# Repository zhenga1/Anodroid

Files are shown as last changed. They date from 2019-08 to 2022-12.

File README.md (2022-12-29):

# Anodroid
v1_0_0
# We do not recommend this project to be used yet. It is only in its beginning stages and does risk failure. 

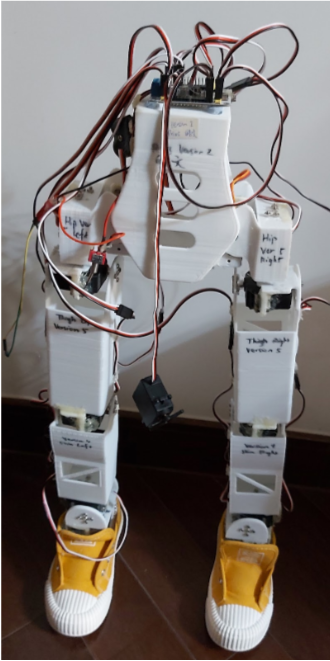
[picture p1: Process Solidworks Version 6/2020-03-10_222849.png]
<br/><br/>
Anodroid is a 10-DOF humanoid-robot. It is an integrated machine that can move around in flat and tilted surfaces. It consists of:
- 15 single axis model motors. 12 needed, 3 for backup
- 24 Circular rotating shafts for the motors, 12 needed, 12 for backup 
- 70 M3*7 screws and nuts, 60 needed, 10 for backup
- 20 sets of axial motor equipments, including an M3*10 screw, a rotating axis, and an M3 nut
- 70 M3*5 nuts and screws, 60 needed, 10 for backup
- An arduino controller board
- 60 sets of nuts and bolts for M4*8 screw, used to secure the screw and motor. 50 are needed, 10 are for backup
- Many rolls of PLA plastic, used for 3D printing
- A 3D printer and 3D printing software

Ideally, one should also have a recent version of DS Solidworks. 

The design files can be found in the root directory.

The **aim of this project** is to eventually allow the robot to posesss the ability to run and walk dynamically on flat and tilted surfaces. 

# EDIT: 
Anodroid is now a 12-DOF humanoid-robot. Two have been added on between the foot and shin parts to allow the robot to tilt left and right

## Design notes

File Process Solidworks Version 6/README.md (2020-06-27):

# Anodroid
v1_0_0
# We do not recommend this project to be used yet. It is only in its beginning stages and does risk failure. 

GitHub Logo
Anodroid is a 10-DOF humanoid-robot. It is an integrated machine that can walk and run, in flat surfaces, in tilted surfaces etcetera. It consists of:
- 13 single axis model motors. 10 needed, 3 for backup
- 20 Circular rotating shafts for the motors, 10 needed, 10 for backup 
- 60 M3*7 screws and nuts, 50 needed, 10 for backup
- 20 sets of axial motor equipments, including an M3*10 screw, a rotating axis, and an M3 nut
- 60 M3*5 nuts and screws, 50 needed, 10 for backup
- An arduino controller board
- 50 sets of nuts and bolts for M4*8 screw, used to secure the screw and motor. 40 are needed, 10 are for backup
- Many rolls of PLA plastic, used for 3D printing
- A 3D printer and 3D printing software

Ideally, one should also have a recent version of DS Solidworks. 

The design files can be found in the root directory:

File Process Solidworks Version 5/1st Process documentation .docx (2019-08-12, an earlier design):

Documents: Data in this laptop, kept in Computer/Documents(E:)

Process 1: Drawing the SR-1501:

Base of the diagram:

Assumptions:

- Assumed outside rectangle fillet radius 2.5
- Assumed tangency of the circles in the sides of the motor

Measured:

- Radius of the circle for the screw on the top of motor:2.34mm
- Distance of the circle for the screw to the center: 7.05mm
- Radius of the big circle on the top:20mm
- Thickness of the upwards circle: 2.06mm
- Side shape top length: 11.78mm
- Side shape middle length: 16.74mm
- Height of the bottom part of the spinny thing:3.6mm
- Height of the bottom part: 4.9mm
- Distance between the outside tangent part of circle to circle:1.84mm
- Radius of the bottom part of the upwards circle: 8.08mm
- Bottom shape length: 9.5mm
- Distance between the top of the upwards circle and the bottom: 6.3mm
- Width of the whole part:3.24mm
- Distance to the ends: 2.95
- Thickness of Holder: 2.2mm
- Connecting holes with Holder:4.32mm diameter

Wrong Assumptions:

- Assumed tangency of the circles in the sides of the motor, not tangent.

Holder motor hole to ends distance: 9.01mm

Actual motor hole to ends distance: 10mm

Height of motor assembly final:

51.5mm+ axis(1mm) = 52.5mm

Holder documentation:

Radius of circles: 2.76

Distance between them: 7.08

Connecting hole with Motor SR-1501: 3.8 diameter

Wrong

Holder dimensions are exactly the same as that of motor hole

Holder center to the end dimension: 42.4mm

Holder bottom holes: Radius 2.34 and distance between each other 9. Vertical with origin and distance from top is 23.

Pelvis:

- Length of motor hole: Original length+1+2*2+6 = 52. 5+4+1+6= 63 .6

Solidworks Feet specifications:

- Shell thickness: 2mm
- Length: 15mm
- Width: 5-7mm
- Shoe: Height of the highest is 6-7mm, max at the ends and min in the middle Max height distance is 4 and 3 respectively
- Shin Basic Documentation:
- Width of shin: Motor length + shell*2 = 52.5+2*2 = 56.5mm
- Width of shin should actually be motor length* shell*2 = 51.5+1+2*2 = 56.5
- Height of shin: 150mm
- Length of shin: 100mm
- Dimension of the shell thing: Multi-variable. 3mm for bottom and 1.7mm for everywhere else.

Shoe:

- Current dimensions only allow 33.7 space
- I want 39.24 space

Thigh Dimensions:

Height: 200mm

Length: 60mm

Width of shin: 51.5+2*2 = 55.5

Shell thickness: 2mm everywhere and 3mm at the bottom.

Additional space given for motor to turn: 39.24

Total amount of exact space needed: 38.24

Solidworks notes:

Properties:

- Rotate Entities: When you have two distinct distance dimensions between two points, that somehow rely on factors such as horizontal and vertical projections and shit. Thus, if you may need to rotate make sure you change these distances. This may include swapping them around, if the rotational angle is 90 degrees

Putting a point in the intersection of a line and a spline:

- Coincide the point with the line first, and then with the spline afterwards. Do this separately

Putting a point in the intersection of a line and a circle:

- Select all three sketch entities, and choose “make intersection”.

Chest Documentation:

1. Dimensions provided 30*17mm. My dimensions 54.5*20mm. Thus, need to make my thing a lot taller

2. Actual height of motor: 51.5mm

3. Their given space: 47mm - 2*2.7mm = 47mm - 5.4mm = 41.6mm. Thus, it needs to be 5.48mm wider. That halved is 2.74mm

Screw documentation:

Screw diameter measured major axis(including the thread): 2.94mm

Screw diameter minor axis: 2.34mm

Screw top(bolt part) width: 5mm

Screw length: 8.64mm

Screw head length; 2.04mm

Bottom of head of screw – End of screw fastener: 8.64-2.04 = 6.6mm

Amount of revolutions of the screw thread(螺纹数量): 12

Pitch of the screw thread(螺距):6.6mm/12 =0.55mm

Height of screw thread: 0.3mm

Length of my triangle for sweep cut: 0.52mm(basic trig)

Thread basics:

Major axis:

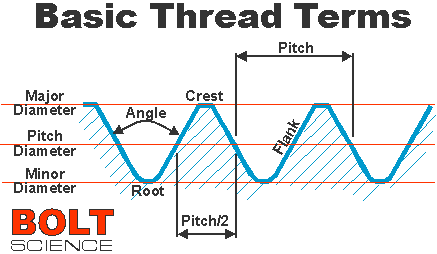
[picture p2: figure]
Image result for thread flank

Lead: Distance of screw threads along the axis that is covered by one complete rotation of the screw （周期）

Pitch: Distance between the crest of a thread to the next(螺距)

Typical screws are triangular, in the sense that the crest and the minor, the thread-form resembles a triangle, typically a isocellles one. This is called the “V- thread”

Male and female defines the direction in which the crest is facing(external-male) and (internal-female)

The M, denotes the largest diameter of the screw, the diameter of the major axis. Thus, M3 means 3 millimeters on the major axis

The second measurement denotes the pitch length, say 1.5mm.

The final measurement denotes the distance between the bottom of the head of the screw to the end of the fastener of the screw. This is, for instance, 30mm.

Very Useful image:

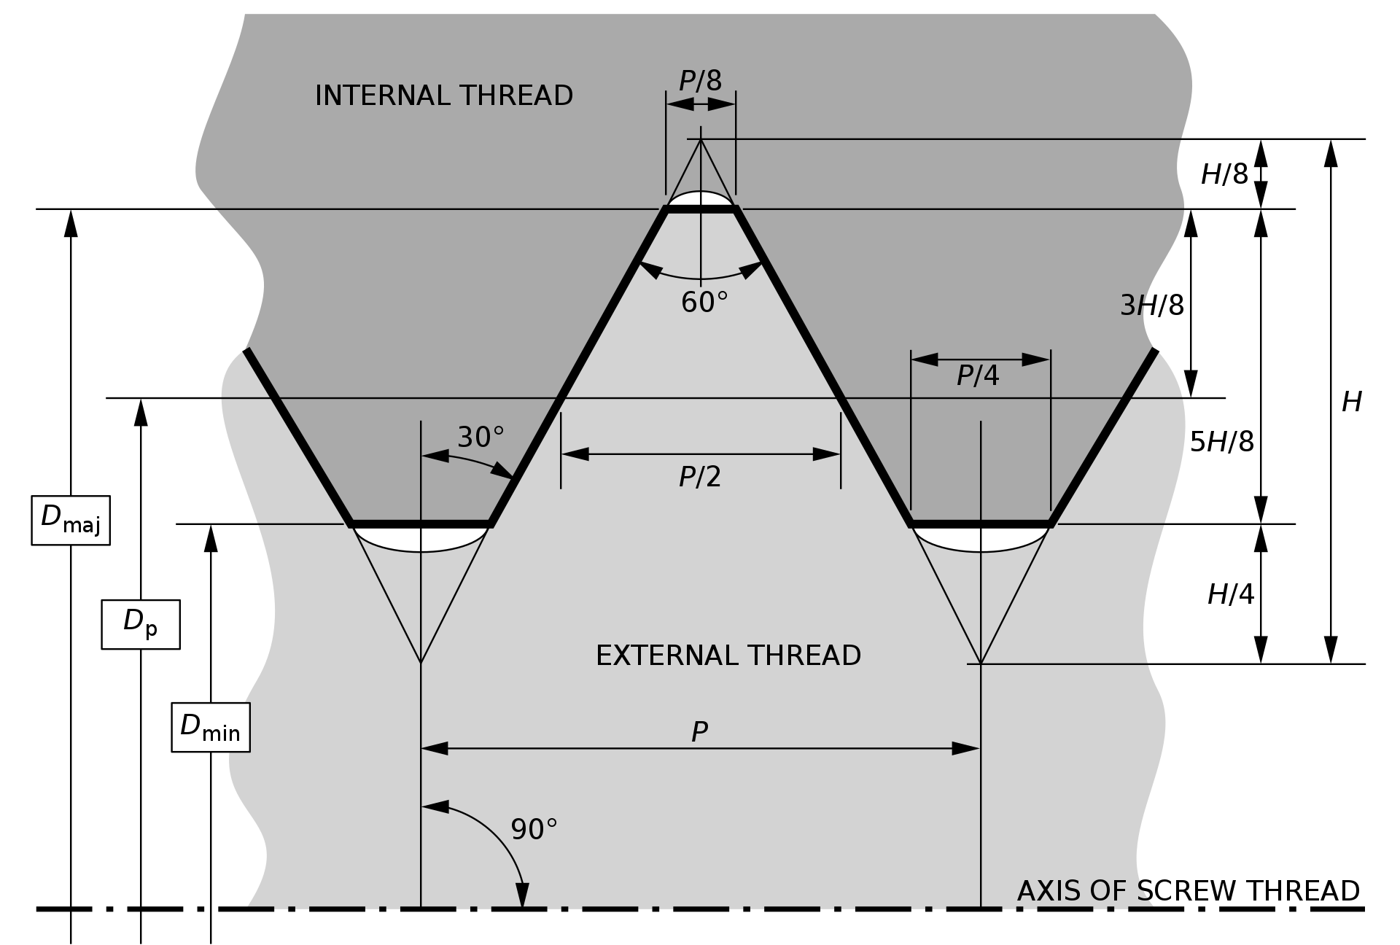
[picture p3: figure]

D – Denotes distance of major, pitch and minor diameter

P – pitch

H- height of screw

Types of screws that are necessary:

M3 screws and M4 screws

Solidworks problems:

- Cannot successfully rotate entities in sketch whilst keeping relations(no matter what)
- Cannot rotate a goddamn plane, say, 90 degrees around it’s origin
- Cannot delete coincident endpoints of two collinear lines.

Solidworks skills:

Special things:

Sketch flange:

https://www.youtube.com/watch?v=35gBHZ77z0I

Used to lift up the edge part of a sheet metal up vertically. Very cool.

Connector piece: Sheet metal turning radius: 1mm

Edge flange length: 20mm

View perspective will have the dimensions done wrong. Thus we need to disable the view of perspective.

Hip motor dimensions:

- It is primarily made of an intersection body
- Shortest width: 57.5mm
- Longest width required: 66.9mm\

Part 1(Hip connector): stats:

- Added an extrude from the outside of the part

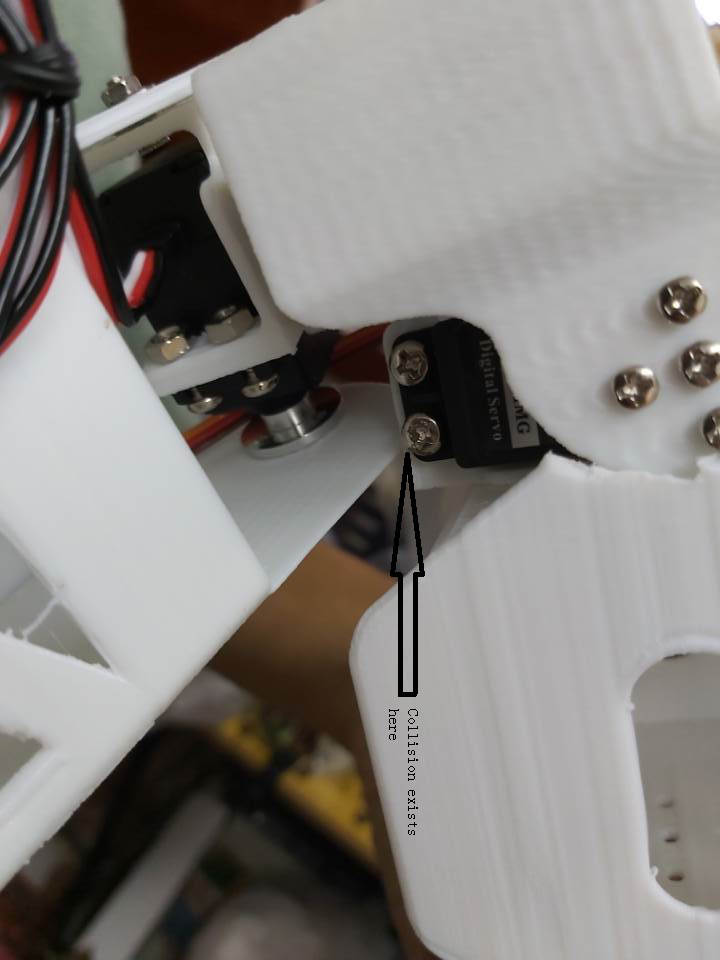
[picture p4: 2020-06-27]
Process Solidworks Version 6/Collisions.jpg

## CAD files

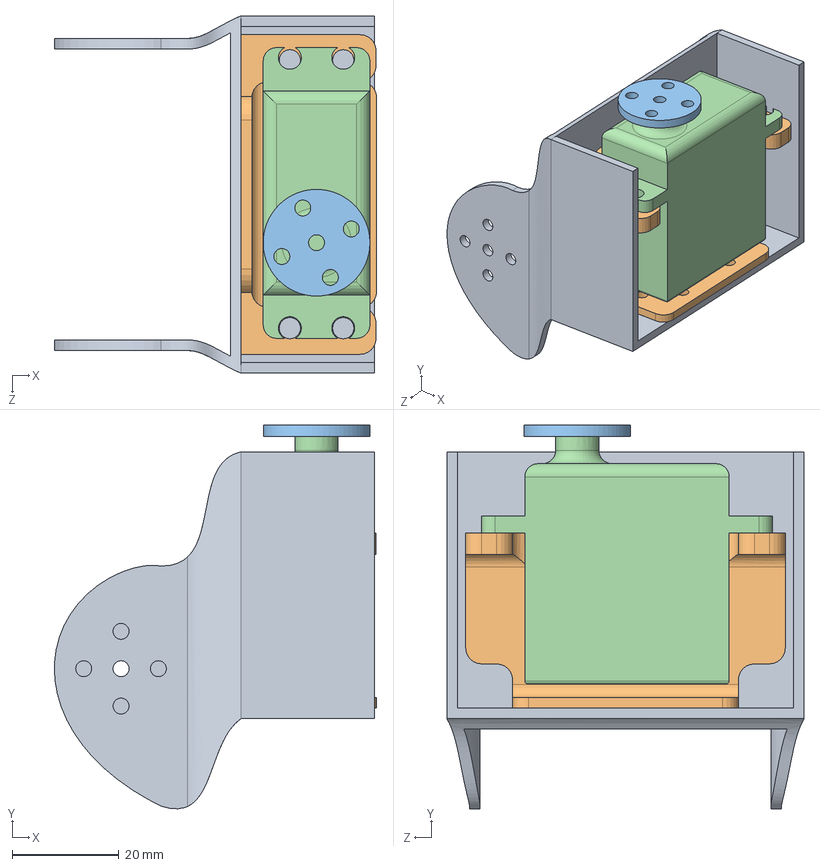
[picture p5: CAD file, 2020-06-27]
Process Solidworks Newest/Replacement Temporary.SLDASM
60.4 x 71.9 x 66.9 mm
hip v5
Holder Right
Top of motor-SR1501
Motor SR-1501

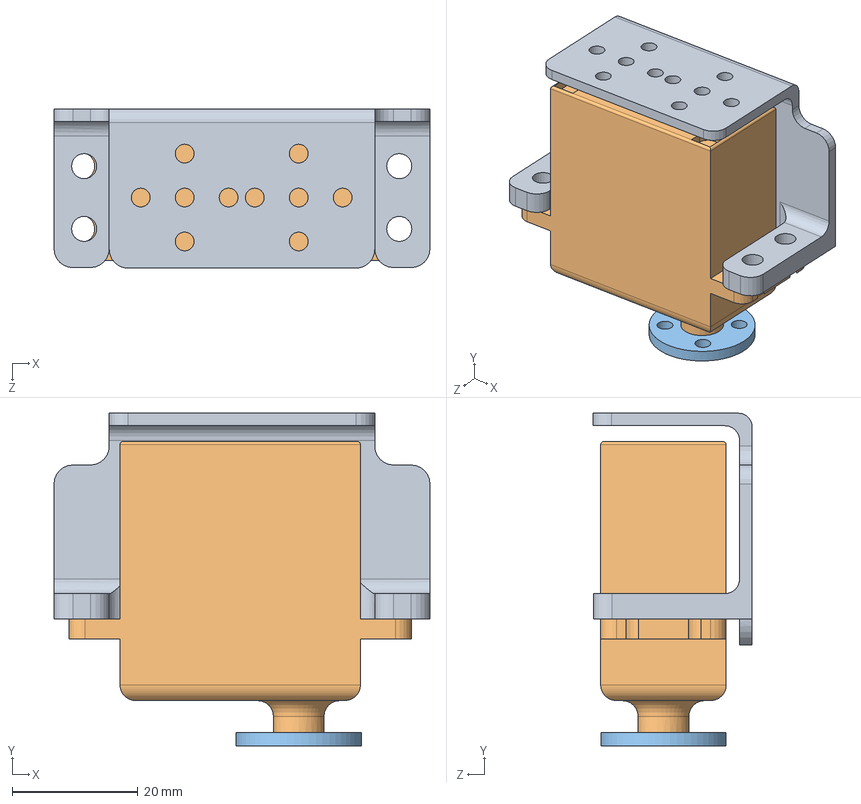
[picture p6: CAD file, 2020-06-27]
Process Solidworks Version 6/Motor assem modified left.SLDASM
59.9 x 53.0 x 25.4 mm
Holder Left
Motor SR-1501
Top of motor-SR1501

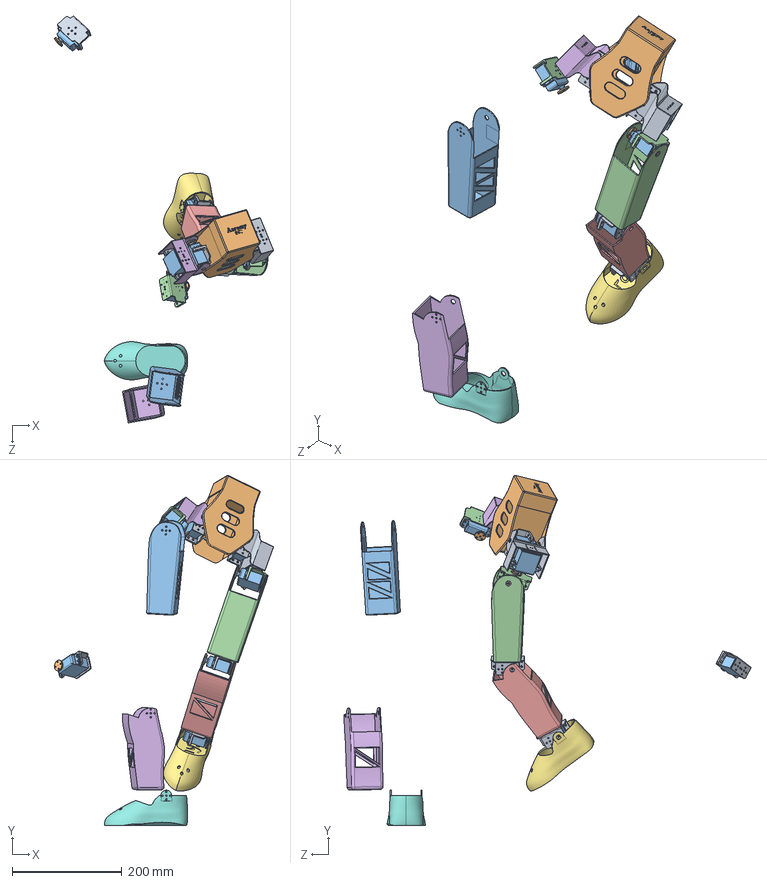
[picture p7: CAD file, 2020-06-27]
Process Solidworks Newest/Assemcomplete.SLDASM
400.0 x 639.6 x 742.8 mm
hip v6
pelvisthing
Thigh left
ThighFirst
Shinmy
Shincpy
Foot right
Foot left
Holder Right x 7
Top of motor-SR1501 x 9
Motor SR-1501 x 9
Holder Left x 2
Major Axis
hip v6 lef

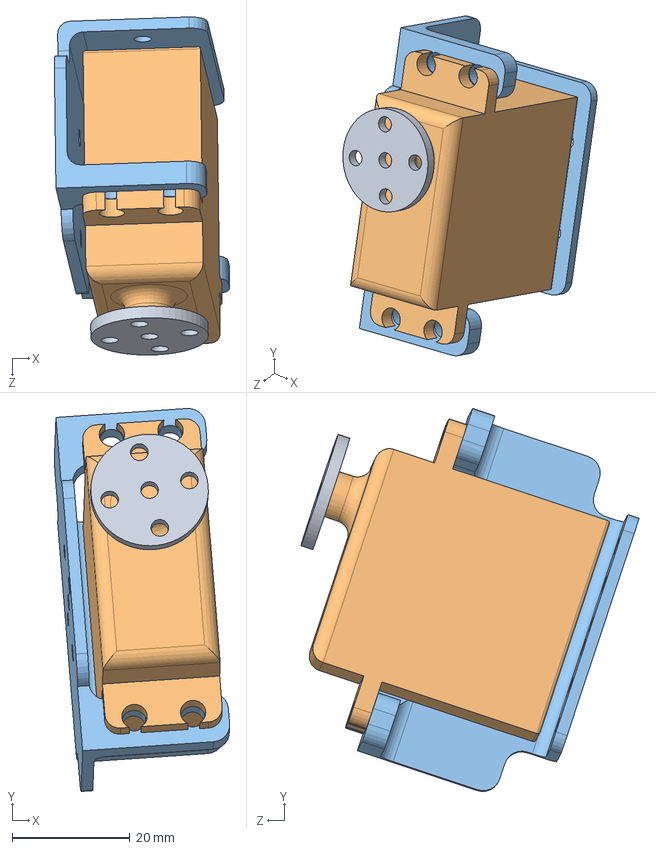
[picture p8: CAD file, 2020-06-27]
Process Solidworks Version 6/Motor Assem left with axis.SLDASM
29.8 x 65.1 x 57.5 mm
Top of motor-SR1501
Motor SR-1501
Holder Right

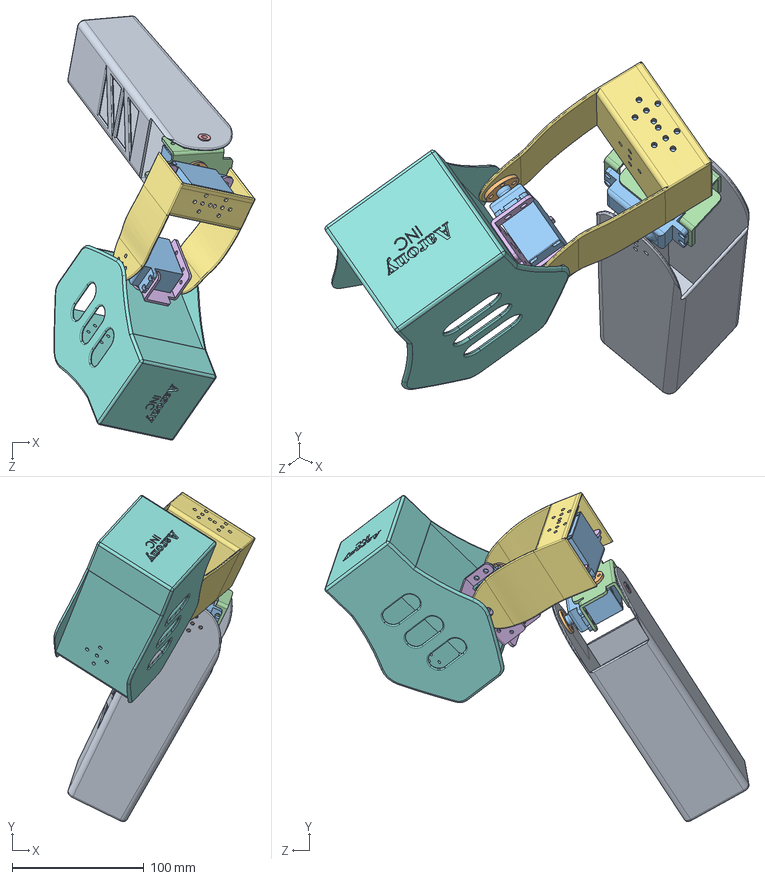
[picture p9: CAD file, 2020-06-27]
Process Solidworsk version 3(incomplete)/Temporary.SLDASM
152.6 x 249.8 x 321.8 mm
ThighFirst
Top of motor-SR1501 x 3
Motor SR-1501 x 3
Holder - Copy
Major Axis
Holder x 2
pelvisthing

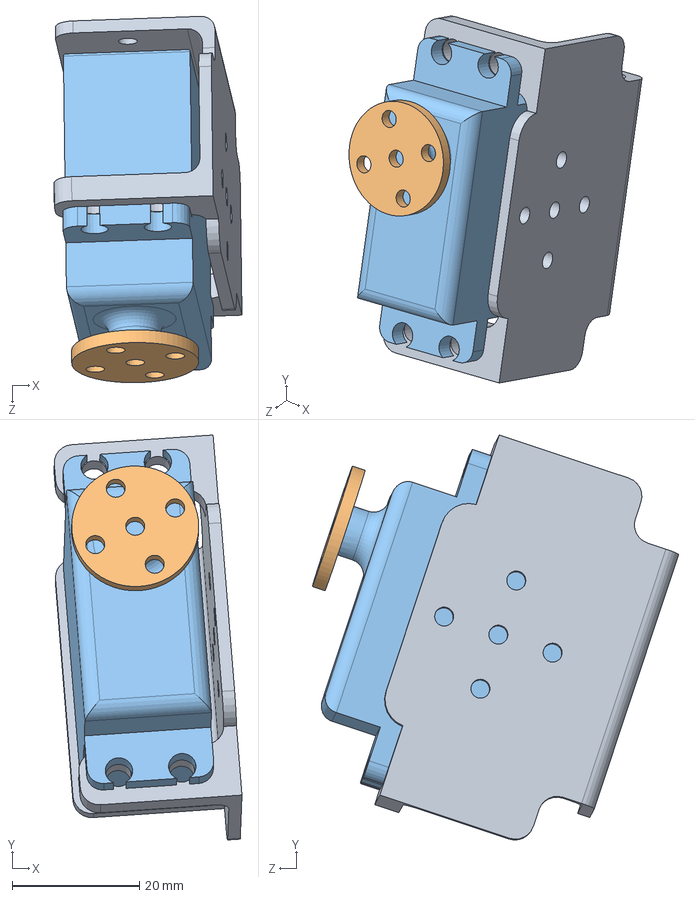
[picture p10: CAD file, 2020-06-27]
Process Solidworks Newest/Motor assem.SLDASM
29.6 x 63.8 x 57.7 mm
Holder Right
Top of motor-SR1501
Motor SR-1501

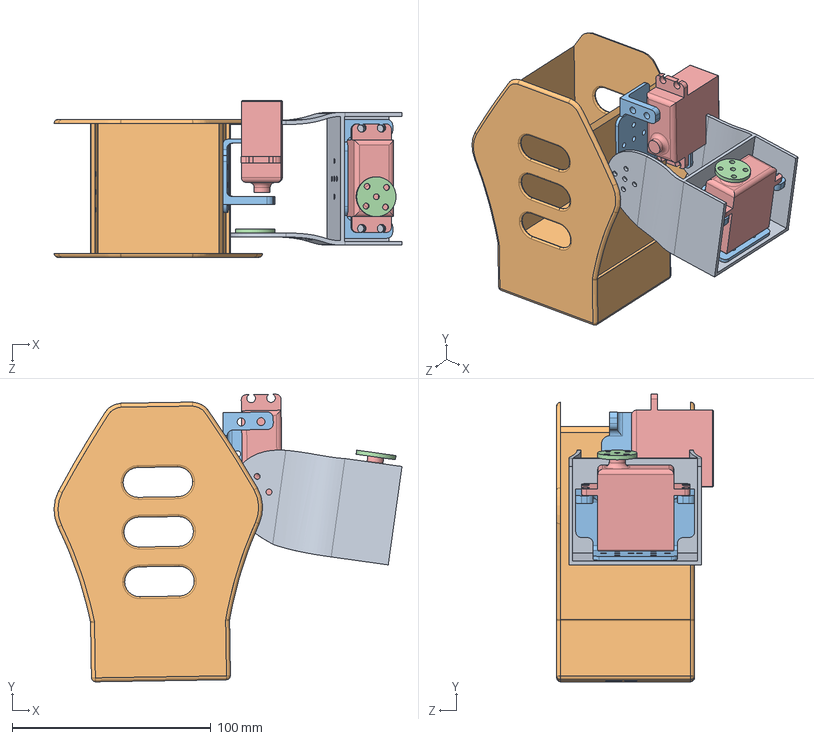
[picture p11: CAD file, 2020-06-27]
Process Solidworks Version 6/Pelvis-hip-thigh-collision-detection-assem.SLDASM
175.1 x 144.7 x 79.0 mm
Holder x 2
Top of motor-SR1501 x 2
Motor SR-1501

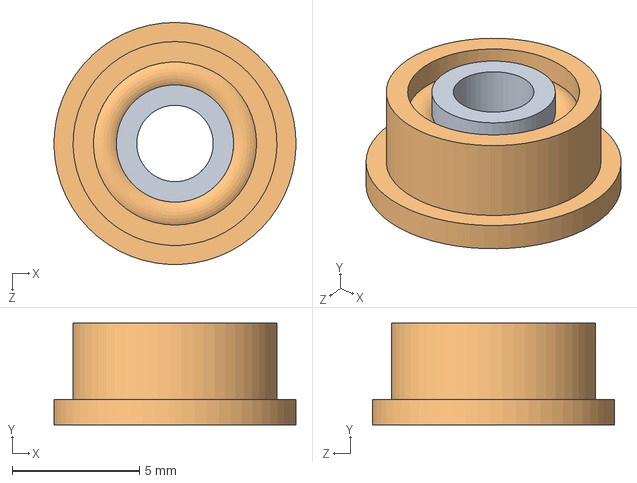
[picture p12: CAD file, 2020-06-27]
Process Solidworks Newest/Axial Rotatory part.SLDASM
9.50 x 4.00 x 9.50 mm
Assisting axis part
Major Axis

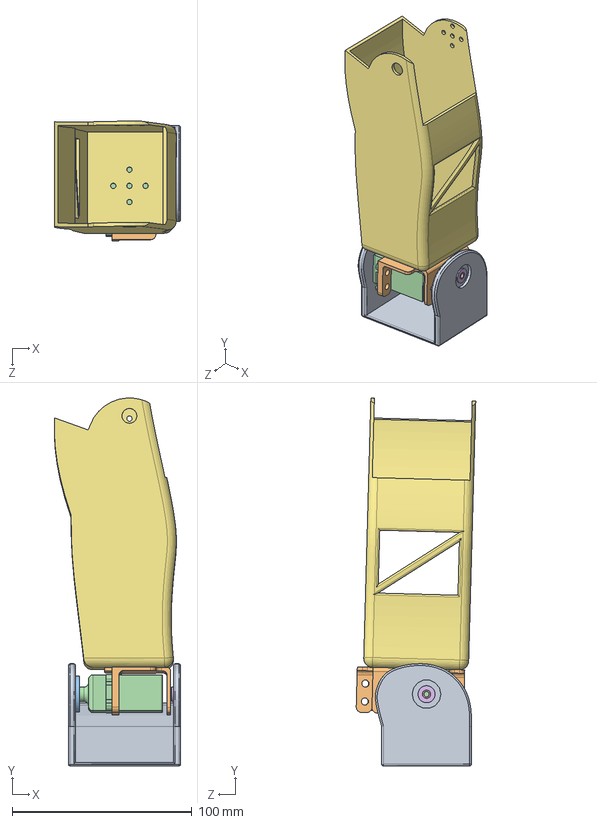
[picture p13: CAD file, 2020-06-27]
Process Solidworks Version 6/Newfootassemwithlengthenedfootjoint.SLDASM
70.3 x 205.0 x 66.6 mm
Lengthenedfootconnectorpart
Holder Right
Top of motor-SR1501
Motor SR-1501
Assisting axis part
Major Axis
Shinmy

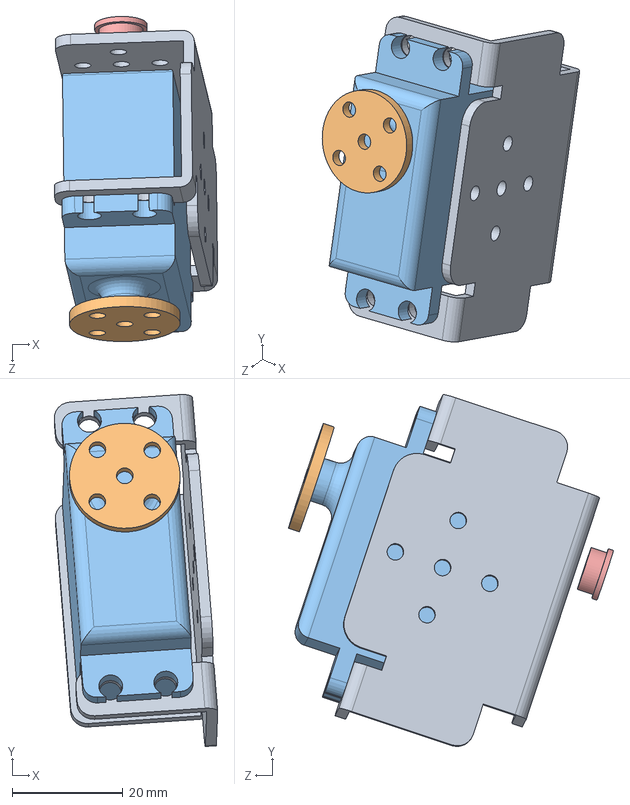
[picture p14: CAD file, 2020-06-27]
Process Solidworsk version 3(incomplete)/Motor assem new with axis.SLDASM
29.5 x 63.6 x 58.8 mm
Holder
Top of motor-SR1501
Motor SR-1501
Assisting axis part
Major Axis

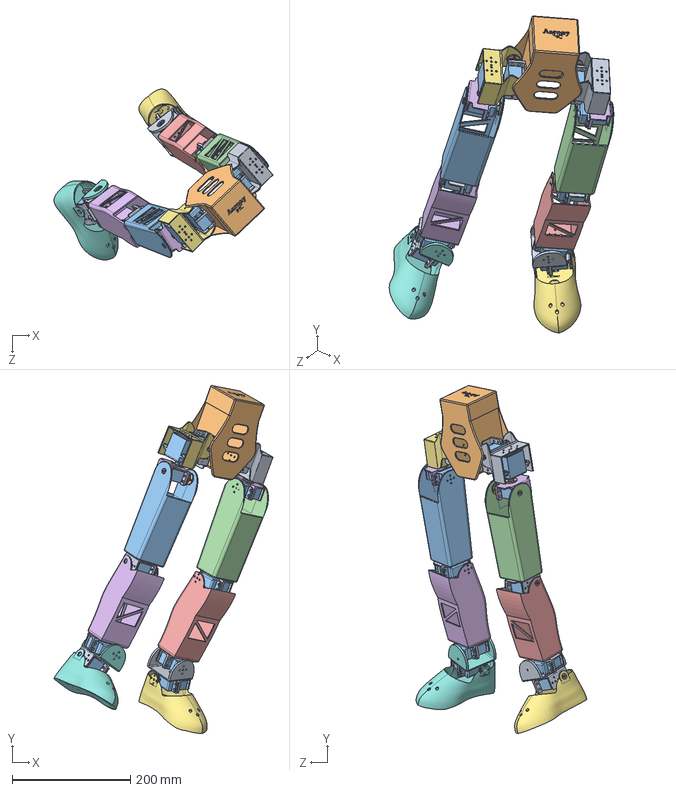
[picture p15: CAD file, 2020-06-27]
Process Solidworks Version 6/Assemcomplete.SLDASM
370.7 x 589.3 x 289.4 mm
hip v6
pelvisthing
Thigh left
ThighFirst
Shinmy
Shincpy
Foot right
Foot left
Holder Right x 10
Top of motor-SR1501 x 12
Motor SR-1501 x 12
Assisting axis part x 4
Major Axis x 6
Holder Left x 2
hip v6 lef
Footconnectorpieceleft
Footconnectorpieceright

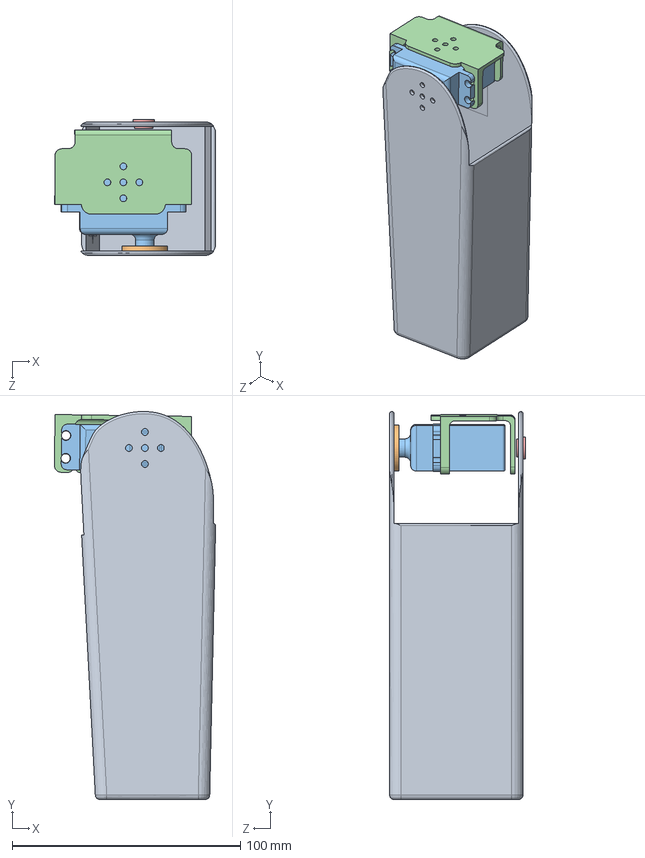
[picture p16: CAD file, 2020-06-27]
Process Solidworks Newest/Thigh Motor assem.SLDASM
70.7 x 170.0 x 59.5 mm
ThighFirst
Top of motor-SR1501
Motor SR-1501
Holder Left
Major Axis

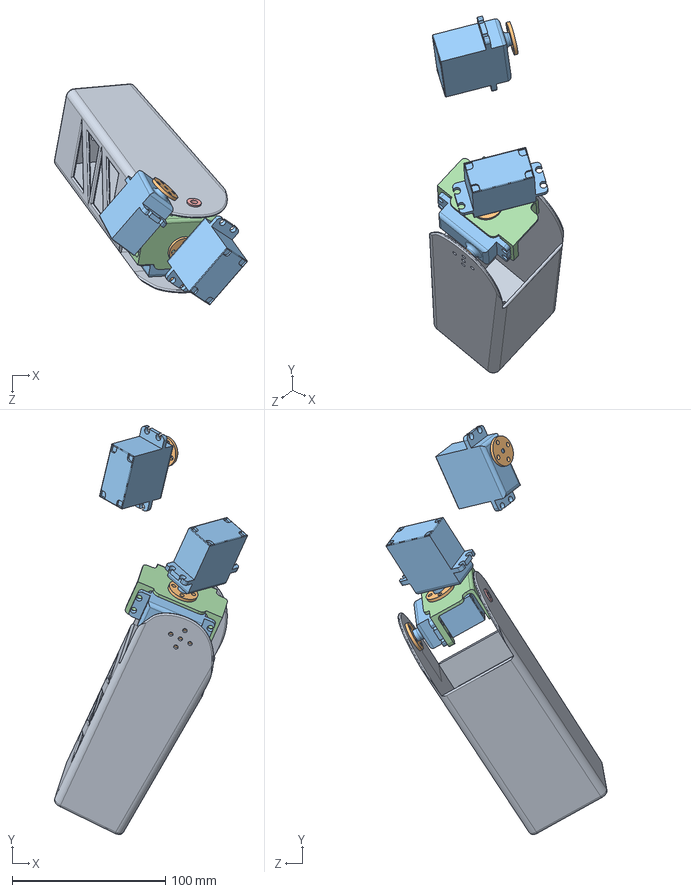
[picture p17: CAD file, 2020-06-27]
Process Solidworks Version 6/Temporary.SLDASM
125.8 x 266.5 x 144.0 mm
ThighFirst
Top of motor-SR1501 x 3
Motor SR-1501 x 3
Holder Left
Major Axis

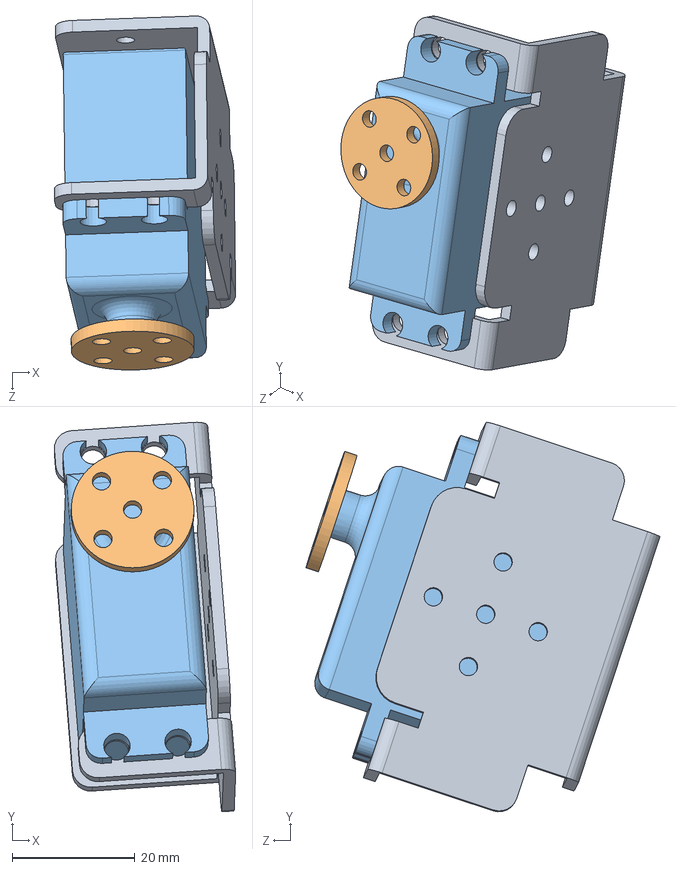
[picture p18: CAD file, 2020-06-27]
Process Solidworsk version 3(incomplete)/Motor assem.SLDASM
29.5 x 63.5 x 57.7 mm
Holder
Top of motor-SR1501
Motor SR-1501

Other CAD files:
Process Solidworks Newest/Motor assembly copy left orientation.SLDASM
Process Solidworks Version 6/Motor assem new with axis.SLDASM
Process Solidworks Newest/Motor assem new with axis.SLDASM
Process Solidworks Version 6/Axial Rotatory part.SLDASM
Process Solidworks Newest/Assisting axis part.SLDPRT
Process Solidworks Newest/Foot left.SLDPRT
Process Solidworks Newest/Foot right.SLDPRT
Process Solidworks Newest/Hip-test-main.SLDASM
Process Solidworks Newest/Holder Left.SLDPRT
Process Solidworks Newest/Holder Right.SLDPRT
Process Solidworks Newest/Major Axis.SLDPRT
Process Solidworks Newest/Motor SR-1501.SLDPRT
Process Solidworks Newest/Motor assem - Copy (2).SLDASM
Process Solidworks Newest/Motor assem - Copy.SLDASM
Process Solidworks Newest/Shincpy.SLDPRT
Process Solidworks Newest/Shinmy.SLDPRT
Process Solidworks Newest/Thigh left.SLDPRT
Process Solidworks Newest/ThighFirst.SLDPRT
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

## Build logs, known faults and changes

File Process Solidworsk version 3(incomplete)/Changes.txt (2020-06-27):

Date Completed: 8/5
Main Changes:

Remeasured and changed the width of the motor-assembly, which was causing problems during assembly. The 
width of the motor-assembly was too short, by 2 millimeters. It was meant to be around 53-53.8mm in length, however
my initial measurements yielded only 51.5.

Reasons for error:
Partially due to inaccurate measurement of Motor SR-1501, including the thickness of the rotatory shaft, and the respective
lengths between the motor holes and each of the ends. This accounted for roughly 0.3-0.4mm of error
Mostly due to the inconsideration of printing inaccuracies: Many distances printed by the 3D printer were longer than they were
meant to be. The thickness of the Holder part itself, for instance, at the ends were meant to be 2mm, however it was printed
2.4mm. The real part's length from the Holder's motor-hole to the ends were also enlarged by roughly a millimetre. Which led to
the error. 

Components affected:
- All main parts apart from Pelvis part, including Foot, Thigh and Shin parts.

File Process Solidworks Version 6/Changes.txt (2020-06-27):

Changes made 27/6/2020:
- Made the foot connector part longer and thicker in comparison
- More complete assembly, names were organised better

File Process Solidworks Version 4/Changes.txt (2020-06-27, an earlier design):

Date Completed: 8/8
Problems:
After testing of new printed parts, I realised that:
1) The hole for my axial bearing is slightly small. The sketch was correct but the 3D-printer shrank my designed hole 
dimension by roughly 0.2-0.3mm
2) The shin part that I designed causes collisions during servo rotations. I considered the collisions between initial servos but didn't
consider possible collisions between the thigh and the shin.
3) The hip part is too big, and when balancing on one foot, can result in a large torque.
4) The holder part needs to be edited as the two sides that come up and connect to the motor are too brittle and too easily broken. 
That part needs to be made thicker.
5) The thigh part is-(possibly too long and needs to be fixed)
6) The hip part has a few motor holes towards the right that are off the mark, and it can cause discrepancies. 
Changes:
1) Expand the diameter by 0.3 to 8.3.

£¨This is partially finished in this version£©(1-2-3-4-5 should be fixed)

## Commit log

2020-06-27 Version 6
    [Assemcomplete.SLDASM, Assisting axis part.SLDPRT, Axial Rotatory part.SLDASM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]
2020-06-27 All the files on Github 27/06/2020
    [Assemcomplete.SLDASM, Assisting axis part.SLDPRT, Axial Rotatory part.SLDASM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]
